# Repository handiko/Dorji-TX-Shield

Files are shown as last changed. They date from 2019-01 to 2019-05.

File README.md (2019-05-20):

# Arduino UNO Shield for Dorji DRA818V/U Transmitter
Dorji DRA818V VHF transmitter module shield for Arduino UNO &amp; compatibles.
This Arduino shield is intended to used as an APRS Transmitter module based on Arduino UNO (see my Arduino APRS [GitHub page](https://handiko.github.io/Arduino-APRS/) or [GitHub repo](https://github.com/handiko/Arduino-APRS). In this version (v.1.0), this board only support low power mode since high power will demand more current and this board only powered from 5V pin of the Arduino (It doesn't obtain power from Arduino Vin pin, yet).

## Photos
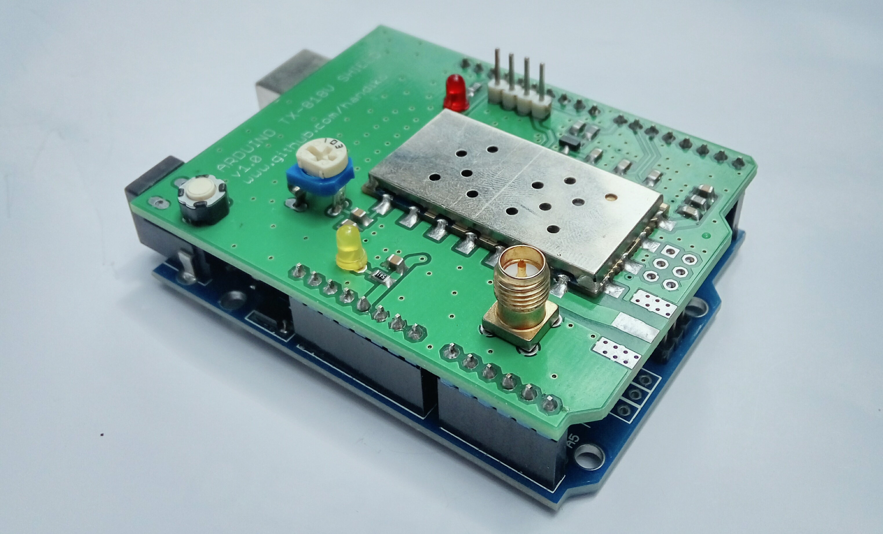
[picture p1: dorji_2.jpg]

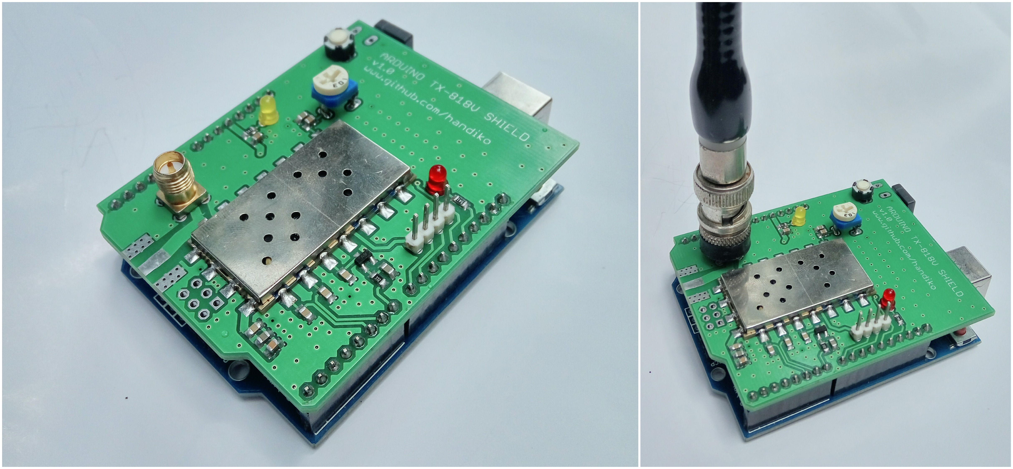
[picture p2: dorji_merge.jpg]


## Pinout
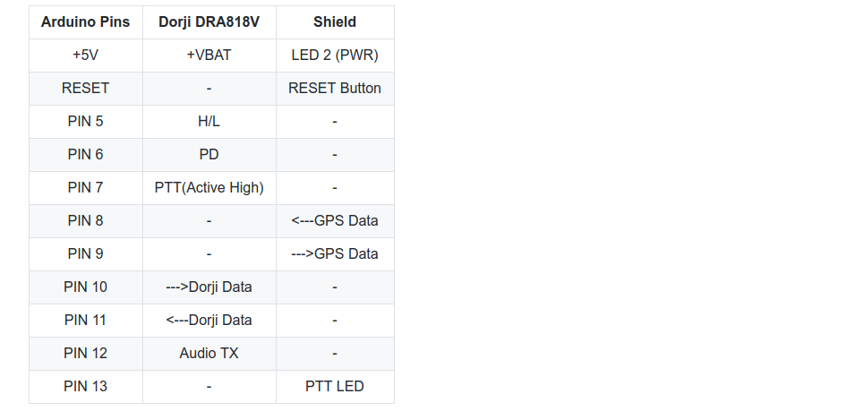
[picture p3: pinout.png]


_Please note that in order to use PIN 8-11 as Serial Data lines, you need to use **SoftwareSerial** library._

## Schematic
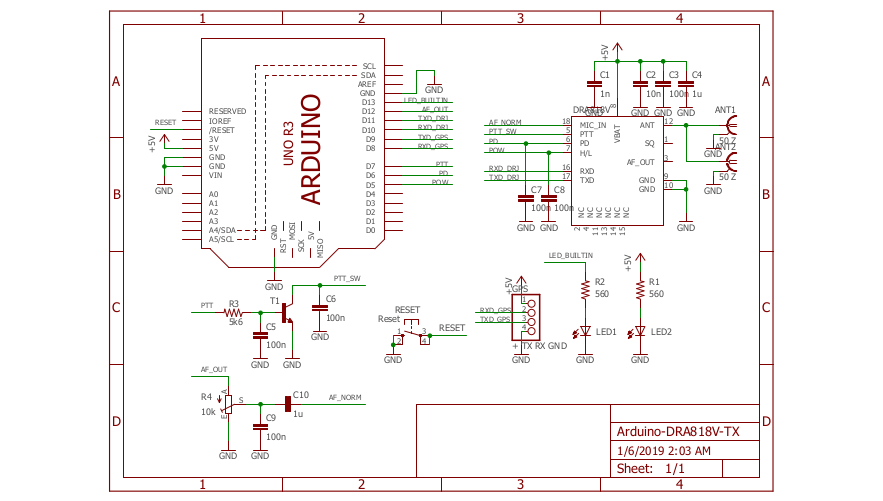
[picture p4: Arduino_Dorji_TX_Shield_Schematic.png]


## TODO
* Adding Silkscreen layer
* Adding ISP port capability
* Adding RX capability (maybe in a different repo..?)
* ...

## Acknowledgements
* Djoko Marjono Susilo - YB1TJ
* Adafruit Proto Shield PCB [GitHub page](https://github.com/adafruit/Adafruit-Proto-Shield-PCB)

## Contributing
1. Fork it [https://github.com/handiko/Dorji-TX-Shield/fork](https://github.com/handiko/Dorji-TX-Shield/fork)
2. Create new branch (`git checkout -b add-blah-blah`)
3. Do some editing / create new feature
4. Commit your works (`git commit -m "Adding some blah blah blah.."`)
5. Push to the branch (`git push -u origin add-blah-blah`)
6. Create a new Pull Request

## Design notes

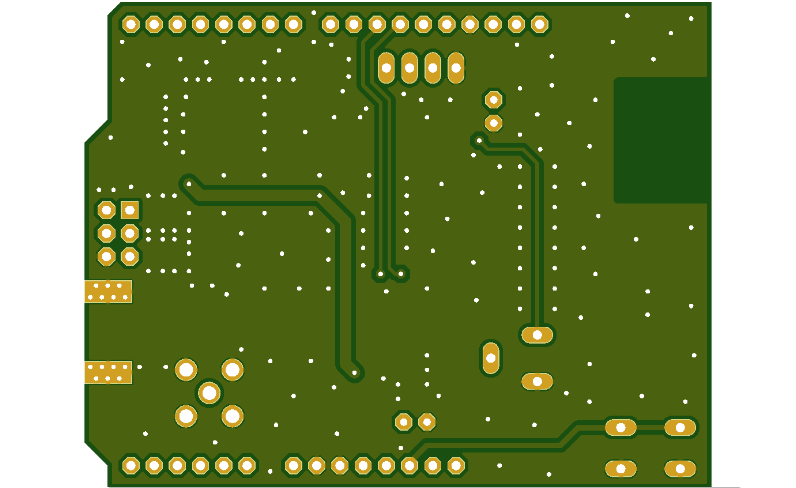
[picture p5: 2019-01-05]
gerber_bottom.png

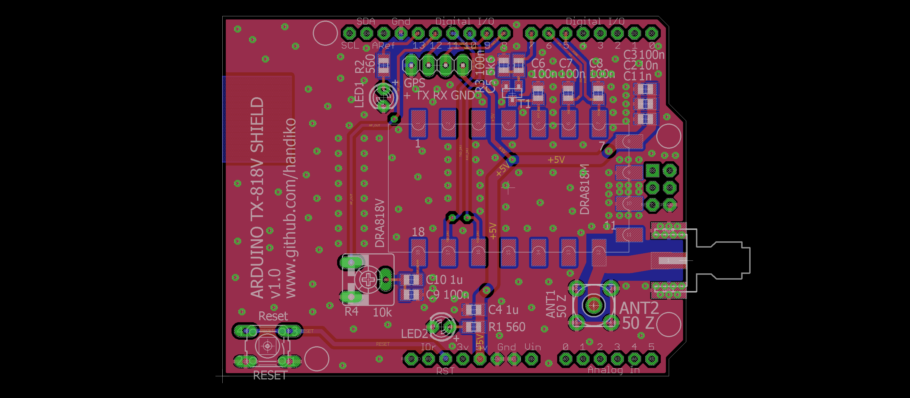
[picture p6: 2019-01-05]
Board_View.png

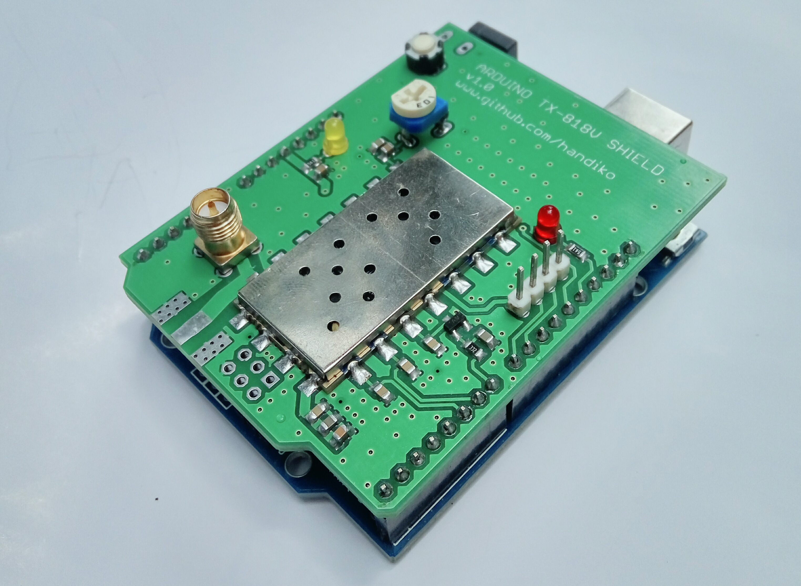
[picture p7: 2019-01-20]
dorji_1.jpg

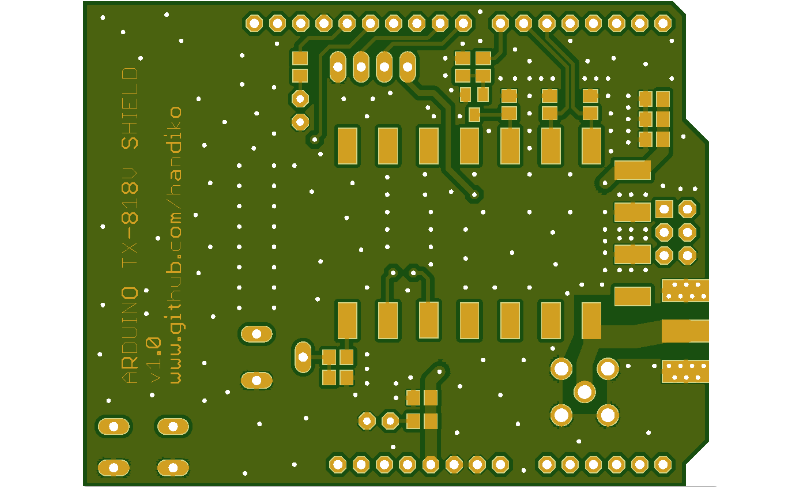
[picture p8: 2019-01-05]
gerber_top.png

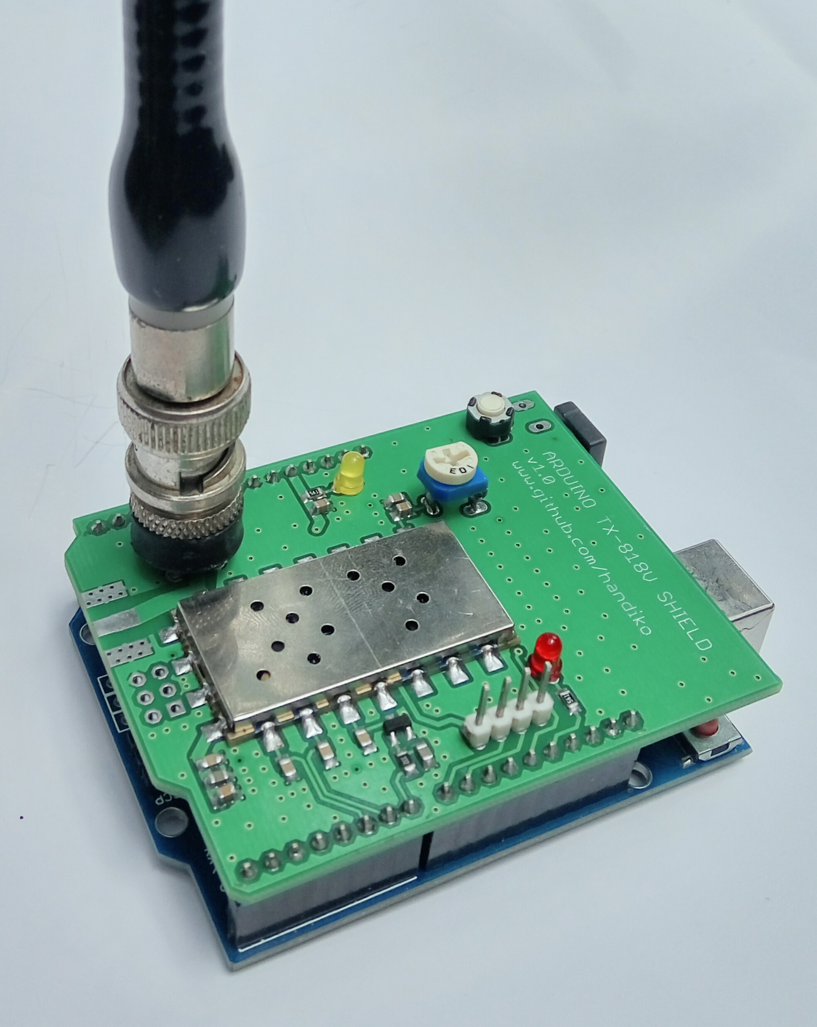
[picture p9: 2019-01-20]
dorji_3.jpg

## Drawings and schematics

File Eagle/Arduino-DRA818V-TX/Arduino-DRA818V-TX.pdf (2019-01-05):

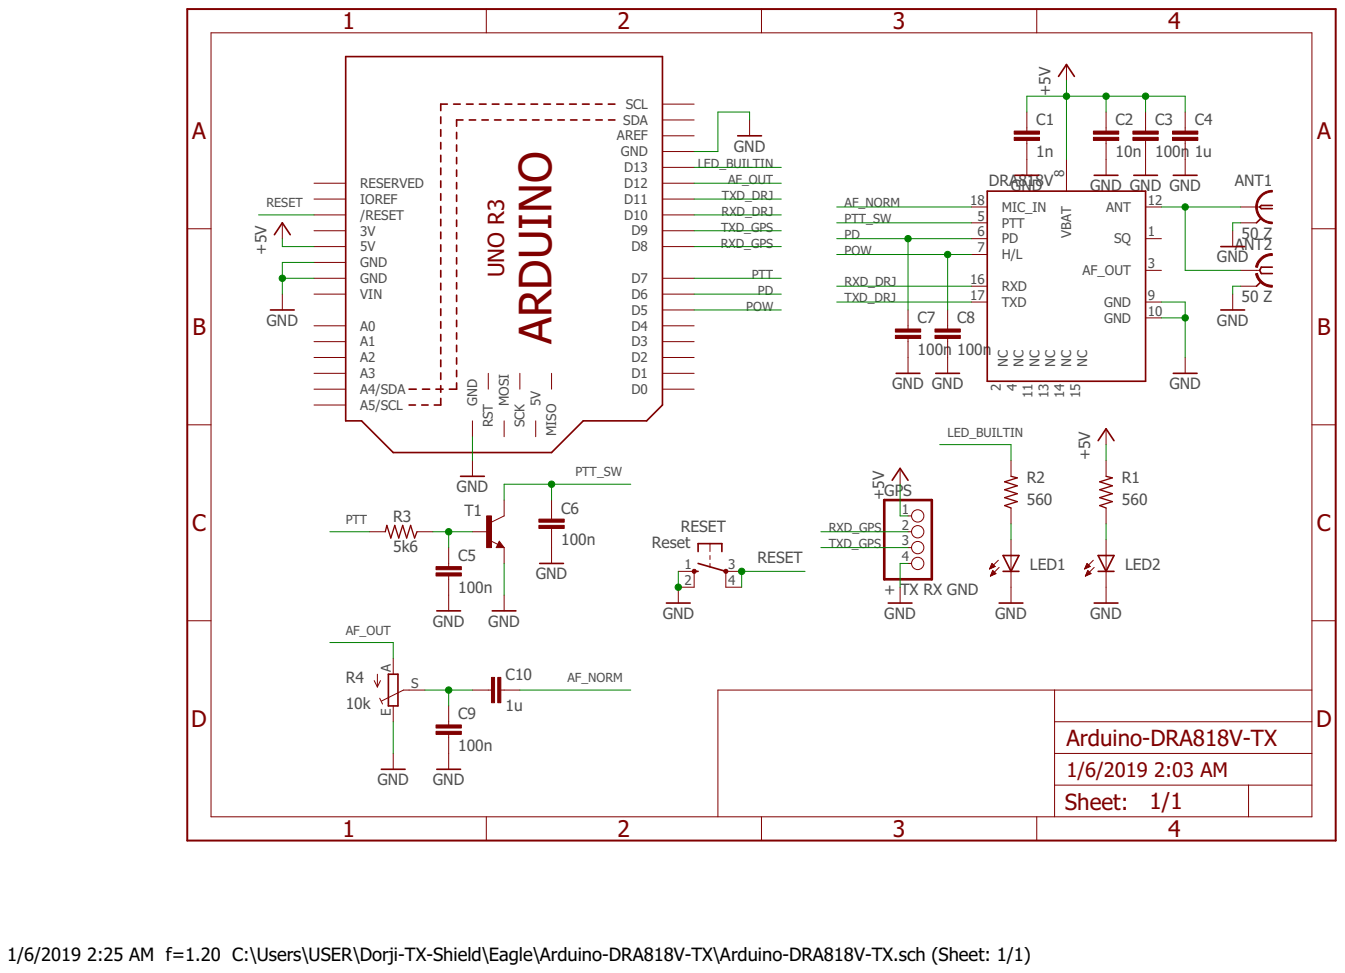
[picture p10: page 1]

1/6/2019 2:25 AM f=1.20 C:\Users\USER\Dorji-TX-Shield\Eagle\Arduino-DRA818V-TX\Arduino-DRA818V-TX.sch (Sheet: 1/1)

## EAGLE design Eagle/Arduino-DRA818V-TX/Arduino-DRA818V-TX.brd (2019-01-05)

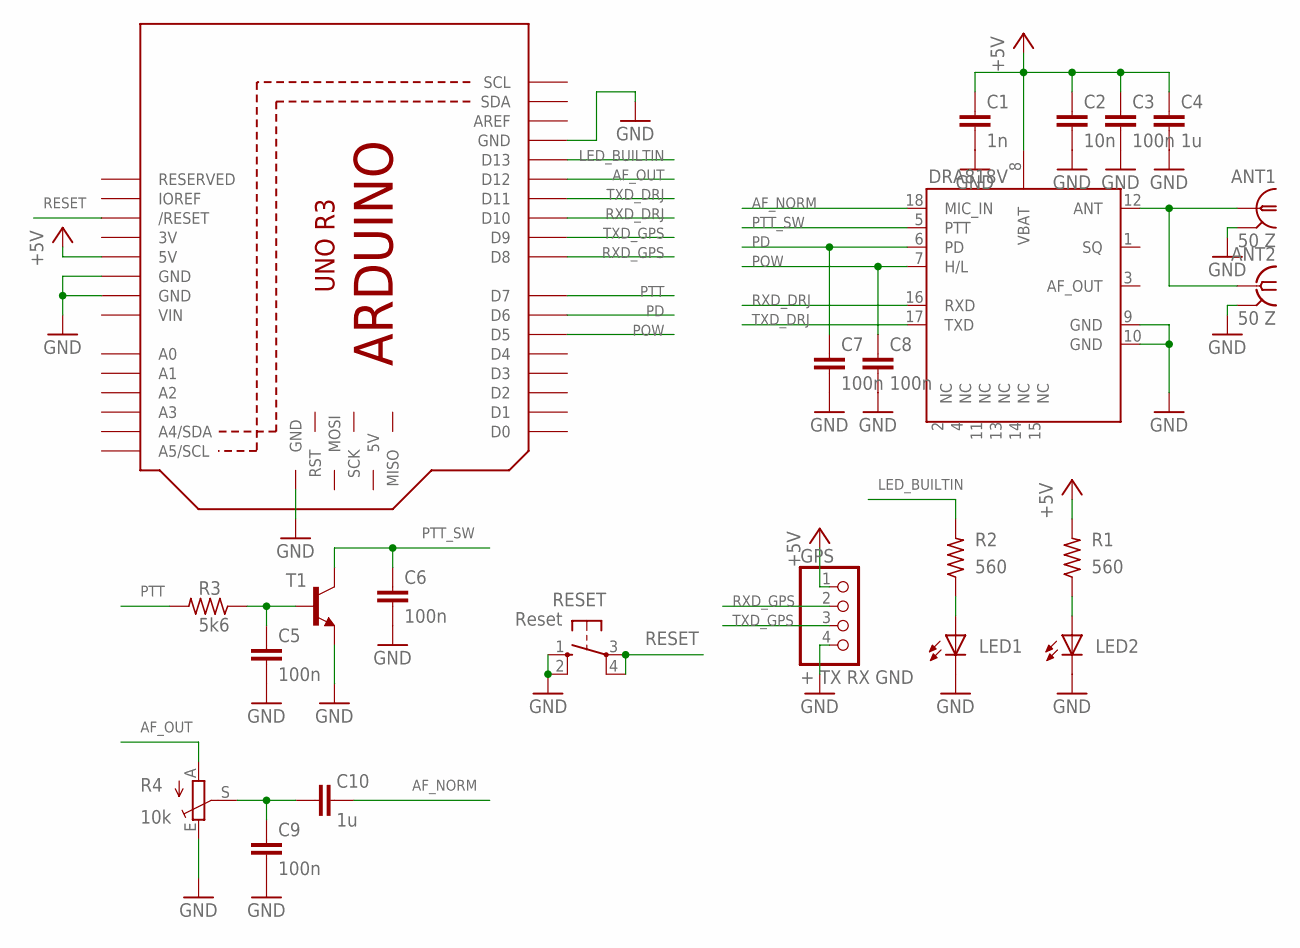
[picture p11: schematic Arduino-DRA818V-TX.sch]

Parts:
ANT1: 50 Z; LTI-SASF54GT
ANT2: 50 Z; J502-ND-142-0701-801/806
C1: 1n; C0805
C2: 10n; C0805
C3, C5, C6, C7, C8, C9: 100n; C0805
C4, C10: 1u; C0805
DRA818V: DRA818A
GPS: + TX RX GND; 1X04
LED1, LED2: LED3MM
M1: ARDUINO_R3_ICSP; ARDUINOR3_ICSP
R1, R2: 560; R0805
R3: 5k6; R0805
R4: 10k; CA6V
RESET: Reset; B3F-10XX
T1: MMBT3904LT1-NPN-SOT23-BEC; SOT23-BEC

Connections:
3V: M1.3V
+5V: C1.1, C2.1, C3.1, C4.1, DRA818V.8 (VBAT), GPS.1, M1.5V, R1.2
AF_NORM: C10.2, DRA818V.18 (MIC_IN)
AF_OUT: M1.D12, R4.A
GND: ANT1.2, ANT1.3 (2), ANT1.4 (2), ANT1.5 (2), ANT2.G@1 (2), ANT2.G@2 (2), ANT2.G@3 (2), ANT2.G@4 (2), C1.2, C2.2, C3.2, C4.2, C5.2, C6.2, C7.2, C8.2, C9.2, DRA818V.9 (GND), DRA818V.10 (GND), GPS.4, LED1.K (C), LED2.K (C), M1.GND, M1.GND@1 (GND), M1.GND@2 (GND), M1.GND@3 (GND), R4.E, RESET.1 (S), RESET.2 (S1), T1.E
LED_BUILTIN: M1.D13, R2.2
unnamed: ANT1.1, ANT2.1, DRA818V.12 (ANT)
unnamed: C5.1, R3.1, T1.B
unnamed: LED1.A, R2.1
unnamed: C9.1, C10.1, R4.S
unnamed: LED2.A, R1.1
PD: C7.1, DRA818V.6 (PD), M1.D6
POW: C8.1, DRA818V.7 (H/L), M1.D5
PTT: M1.D7, R3.2
PTT_SW: C6.1, DRA818V.5 (PTT), T1.C
RESET: M1.RESET (/RESET), RESET.3, RESET.4 (P1)
RXD_DRJ: DRA818V.16 (RXD), M1.D10
RXD_GPS: GPS.2, M1.D8
TXD_DRJ: DRA818V.17 (TXD), M1.D11
TXD_GPS: GPS.3, M1.D9
VIN: M1.VIN

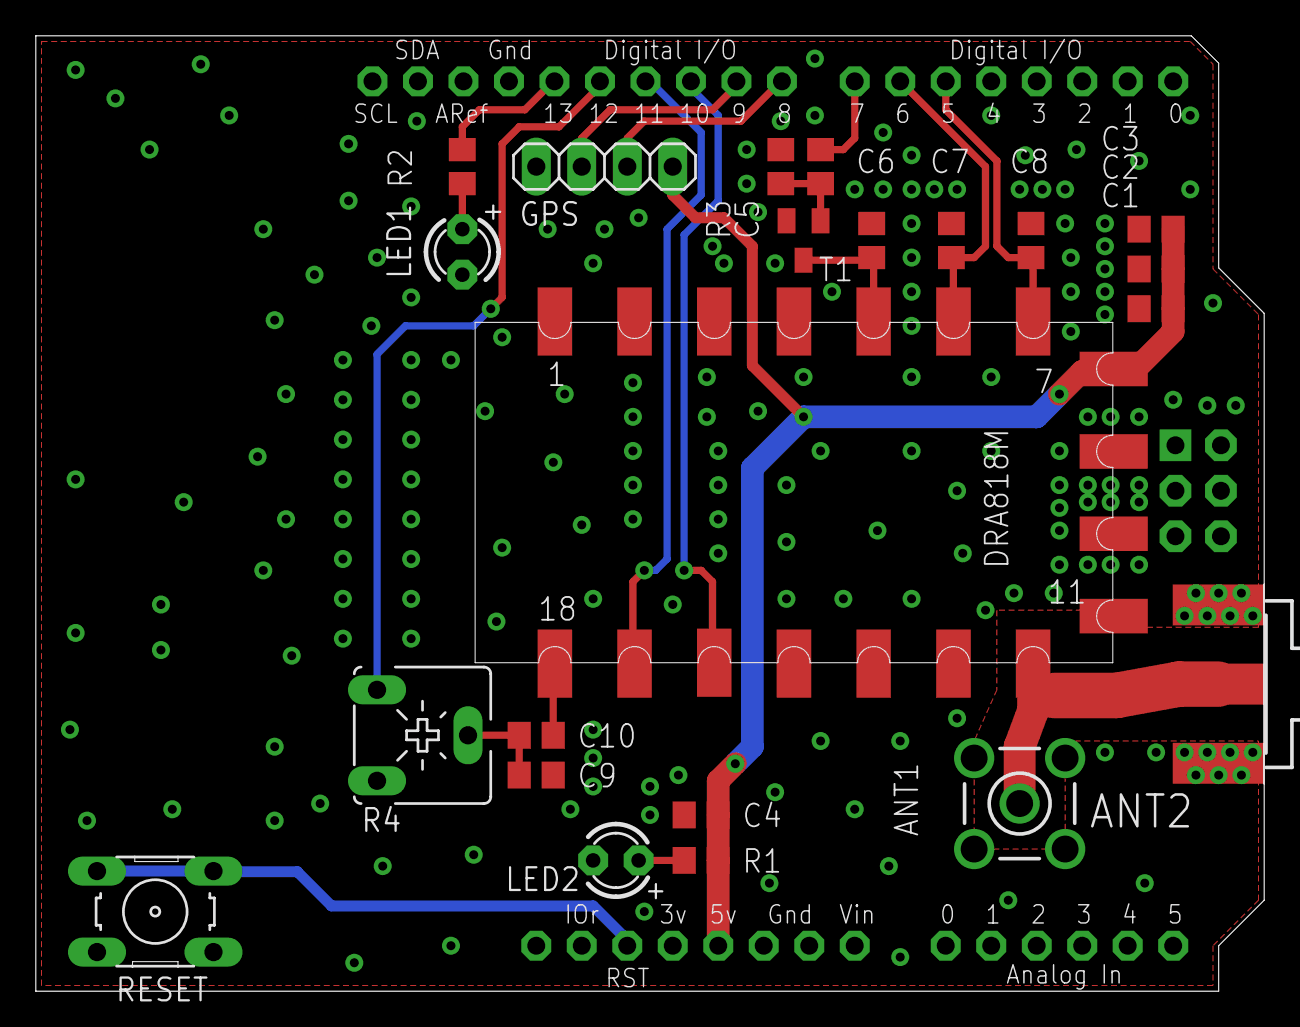
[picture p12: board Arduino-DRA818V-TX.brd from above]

Board: 2 copper layers, 68.6 x 53.3 mm, 23 parts (0 on the bottom side), 19 nets.

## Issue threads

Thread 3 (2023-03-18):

Problems with PTT

TF1987, 2023-03-18:
Hi, have several Problems with the PTT. The DRA818V seems to send all the time, also when PTT is LOW. Can anybody help?

handiko, 2023-03-19:
Was the shield mounted on the Arduino or standalone?

TF1987, 2023-03-19:
Hi Handiko, shield was mounted on the arduino. I wondered because the DRA818V need a voltage of 3,3 V. For your design it becomes the supply voltage of the Arduino (5V).

Also the level of the PTT pin on the side of the transistor is not 5V. What type is T1? It is not written in your sketch.

BR Thomas

handiko, 2023-03-19:
First of all, try your Dorji Shield as a standalone board to eliminate all external causes. Put +5V and GND ONLY via the side connector. You can use +5V from an Arduino to do so, but it can only supply enough current to operate at low power on TX.
The T1 is a generic NPN switching transistor. You can use MMBT3904, MMBT2222, or any SMD small signal NPN transistor (as long as the pinout is compatible). Without the PTT pin of the shield being connected to anything, the base of T1 should be 0V AND the collector of T1 (pin 5 of the Dorji module) is more than 3V.

If the Dorji module is always TX, then it means, the pin 5 of Dorji is somehow pulled down to the ground. Maybe by the failed transistor T1, or there is some stray voltage at the base of T1 turning the transistor ON.

handiko, 2023-03-19:
Ps: what I mean of test the Dorji board as a standalone module, is to remove it from the Arduino board. Don't attach it.
Use jumper cables to connect the +5V and GND from a power supply or an Arduino.

handiko

handiko, 2023-03-19:
Another way to troubleshoot (must be checked in sequence):
1. remove R3 (5k6). If the problem goes away, then it's your Arduino that somehow outputs logic HI on D7. Check it and correct it. If the problem still persists, then,
2. remove T1. If the problem goes away, then it's the T1 which not compatible or failed. Replace T1. At idle, the collector of T1 should be high and at TX it should be low.

TF1987, 2023-03-19:
Thanks. I will try.

Greetings from Germany

handiko, 2023-03-22:
Hi Thomas,

Unfortunately, I don't have any module DRA818V at hand anymore. So I can't really compare your measurements with mine. But I'm sure my previous troubleshooting sequences are based on my past experiences. It could be DRA818V modules nowadays are a little bit different compared with past models. Your voltage measurements at the PTT pin of DRA818V are good, I think.

Maybe you could "force" the collector of T1 high by a pull-up resistor (a resistor from the collector of T1 to +5V) of maybe 4k7 to 47k. That way, at idle, the collector of T1 should be always high. When the T1 is turned on by a high signal on D7, the T1 collector should be pulled low without a problem.

If the problem still exists, I have to say that the module is problematic.

TF1987, 2023-03-24:
Hi Handiko,

Thanks for your reply. I guess I found the problem. I tested the shield without an antenna and it works. In the moment I'll mount any kind of antenna there is much HF-noise on the PTT-pin of the DRA818V. So the pin will not go up to 3,2V anymore. I think I make this problem by my own, because I create a new shield-PCB routing. Maybe the antenna strip on the PCB is routed the wrong way. Maybe it's needed to create a new design...thats not good.

BR Thomas, DO4FT

handiko, 2023-03-24:
Without seeing the PCB layout, it is almost impossible for me to tell whether the layout is "RF compatible" or not. It is a good practice to separate the ANT trace as far away as possible from the PTT trace. Since the RF transmitted by the antenna could couple back to the PTT trace, which could result in PTT hang. We could mitigate this by putting a couple of RF bypass capacitors at the PTT pin of the DRA818V module. These capacitors consist of 22pF +  100pF + 1nF paralleled. Preferably all use SMD capacitors.

All in all, RF PCBs are not as simple as we might think. And the best way to learn is by building our own design. There are plenty of resources out there which would teach us to properly design an RF PCB. Also, we could discuss our discoveries and obstacles here. Happy experimenting!!

radio-satellites, 2025-01-04:
@handiko what is the purpose of the transistor (T1) on the PTT line? And is R4 (on the audio input line) a variable resistor?

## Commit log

2019-01-03 Rearrange folders
    [Arduino-DRA818V-TX.brd, Arduino-DRA818V-TX.sch]
2019-01-04 Adding Dorji Library
    [Arduino-DRA818V-TX.brd, Arduino-DRA818V-TX.sch]
2019-01-04 Polygon re-pour
    [Arduino-DRA818V-TX.brd, Arduino-DRA818V-TX.sch]
2019-01-04 Adding Eagle Template
    [Template.brd, Template.sch]
2019-01-04 Generate Gerber
    [Template.brd]
2019-01-04 Adding Eagle SCH Template
    [Template.sch]
2019-01-04 Adding BRD Template
    [Template.brd]
2019-01-04 Change Info
    [Arduino-DRA818V-TX.brd]
2019-01-04 Generate Gerber files
2019-01-05 Using 0805 SMDs
    [Arduino-DRA818V-TX.brd, Arduino-DRA818V-TX.sch]
2019-01-05 Adding board view pic
